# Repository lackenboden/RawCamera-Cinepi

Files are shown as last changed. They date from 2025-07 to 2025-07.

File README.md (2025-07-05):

# Compact 3D printed enclosure/sensormount for a barebones IMX585 [Cinepi](https://github.com/cinepi/cinepi-raw) camera.

Everything

## Features:

    • Spring adjustable C-Mount
    • Raw recording Capabilities (4K 12Bit - 1/1.2 inch sensor)
    • Internal Storage on NVME 2280 SSD
    • NPF battery compatibility
    • Display via Smartphone
    • Lots of mounting points for addons

## Software

>	[Cinemate](https://github.com/Tiramisioux/cinemate/tree/main) by Tiramisioux - A simple gui built ontop of cinepi-raw for control via wifi or screen <br>
>	 [Cinepi-raw](https://github.com/cinepi/cinepi-raw) by Schoolpost - Image capture and control interfaces - Makes raw recording possible
>	<br> <br>
>	Thanks for providing the software for us ♥

## Addons (for now):
Addons

    • Grip
    • Adaptor for a DJI ronin RS3 phoneholder

## Printing Materials

    • Use a material of your liking for most of the parts
    • TPU of softness of at least 88A (Springs and Rubbercover need to be printed from TPU)

## BOM:
**1x CinepiCamera_Straight_Mainbody.stl**<br>
	&nbsp;&nbsp;&nbsp;&nbsp;6x ruthex - RX-1/4-20x12,7 – Quarter inch threaded inserts<br>
	&nbsp;&nbsp;&nbsp;&nbsp;8x ruthex – RX-M3x5_7 – M3 threaded insert short<br>
1x Adjustablemount_C_Springs_2 (assembly)<br>
	&nbsp;&nbsp;&nbsp;&nbsp;1x SE-SB8M-IMX585 (notes in assembly guide)<br>
	&nbsp;&nbsp;&nbsp;&nbsp;**3x Adjustablemount_C_Springs_TpuSpring.stl** !Caution print in 88A or similar TPU!<br>
	&nbsp;&nbsp;&nbsp;&nbsp;3x M2x10 flat head screw<br>
	&nbsp;&nbsp;&nbsp;&nbsp;**1x Adjustablemount_C_Springs_Rubbercover.stl** (notes in assembly guide)<br>
	&nbsp;&nbsp;&nbsp;&nbsp;**1x Adjustablemount_C_Springs_Gluebase.stl** (notes in assembly guide)<br>
	&nbsp;&nbsp;&nbsp;&nbsp;**1x Adjustablemount_C_Springs__Filterholder.stl** (notes in assembly guide)<br>
	&nbsp;&nbsp;&nbsp;&nbsp;&nbsp;&nbsp;&nbsp;&nbsp;	1x IR-Cut Filterglass (18x15mm)<br>
	&nbsp;&nbsp;&nbsp;&nbsp;&nbsp;&nbsp;&nbsp;&nbsp;  2x M2x4 Flat head screws<br>
8x M2x4 Flat head screws<br>
**1x CinepiCamera_Straight_Batterycompartment.stl**<br>
	&nbsp;&nbsp;&nbsp;&nbsp;1x ruthex – RX-M3x5_7 – M3 threaded insert short<br>
	&nbsp;&nbsp;&nbsp;&nbsp;2x 2.6mm banana plug (notes in assembly guide) – eg. RS: 2080217<br>
	&nbsp;&nbsp;&nbsp;&nbsp;2x ISO 4762 M2x8 cylindrical head screw<br>
	&nbsp;&nbsp;&nbsp;&nbsp;1x CK1408 dcdc 5V stepdown converter<br>
	&nbsp;&nbsp;&nbsp;&nbsp;1x Raspberry Pi 5 B 8GB<br>
	&nbsp;&nbsp;&nbsp;&nbsp;&nbsp;&nbsp;&nbsp;&nbsp;	1x Pineboards HatDrive! Bottom<br>
	&nbsp;&nbsp;&nbsp;&nbsp;&nbsp;&nbsp;&nbsp;&nbsp;	1x Samsung 970 EVO Plus - 2 TB 2280 SSD (or alternatives if compatible)<br>
	&nbsp;&nbsp;&nbsp;&nbsp;&nbsp;&nbsp;&nbsp;&nbsp;	1x Raspberry Pi active cooler for RPI5<br>
	&nbsp;&nbsp;&nbsp;&nbsp;	4x ISO 4762 M2.5x16<br>
	&nbsp;&nbsp;&nbsp;&nbsp;**1x CinepiCamera_Batterydoor.stl**<br>
	&nbsp;&nbsp;&nbsp;&nbsp;1x ISO 4762 M3x10 cylindrical head screw<br>
4x ISO 4762 M3x10 cylindrical head screw<br>
**1x CinepiCamera_Straight_Top.stl**<br>
	&nbsp;&nbsp;&nbsp;&nbsp;3x ruthex - RX-1/4-20x12,7 – Quarter inch threaded inserts<br>
	&nbsp;&nbsp;&nbsp;&nbsp;4x ruthex – RX-M3x5_7 – M3 threaded insert short<br>
4x ISO 4762 M3x10 cylindrical head screw<br>
<br>
Sony NP-F750 batteries (or other sizes of batteries – NP-F750 is flush with the camera)<br>
<br>

## BOM Addons:

**1xCinepiCamera_Straight_Grip.stl**<br>
	1x ruthex - RX-1/4-20x12,7 – Quarter inch threaded insert<br>
4x ISO 4762 M3x10 cylindrical head screw<br>
<br>
**1x CinepiCamera_Straight_RoninPhoneholder.stl**<br>
	1x ruthex - RX-1/4-20x12,7 – Quarter inch threaded insert<br>
1x Tripod screw with cylinder head (or fitting alternatives)<br>
<br>
<br>

## Assembly guide

## Converting the CS Mount on the IMX585 Board to C Mount

CS-Mount Soho
CS-Mount Soho Back
<br><br>
>Remove the M2 screws from the back of the IMX585 PCB<br>
>Preheat your 3D printer bed to the maximum level supported by it (without destroying your printer bed) - I used 120 °C<br>
>Place down the aluminum mount face down onto the hotbed and leave it there for a few minutes to weaken the glue<br>
>
>Use a sharp prying tool to remove the aluminium mount from the pcb while still warm - Start prying on the edges - Dont use too much force!<br>
<br>

Cs-CmountIMX585_5

>Use a M2 screw (or tap) and form the threads on the **Adjustablemount_C_Springs_Gluebase.stl** (pictured red)
>Use glue or silicone (neutral cure to not damage the aluminium?) and fix it to the removed CS mount
<br>

Filterholder Exchangable

>Cut the IR Filterglass to size (18x15mm)
>Glue it to the **Filterholder Exchangable.stl**

Cs-CmountIMX585_4

>Use three **Adjustablemount_C_Springs_TpuSpring.stl** and M2x10 screws and fix the sensor to the mount<br>

Cs-CmountIMX585_2

>Add the **Adjustablemount_C_Springs_Rubbercover.stl** by using either M2x8 screws or glueing it to the sensor board<br>
>Use electrical tape or similar to remove light leaks after adjusting the mount<br>

<br>
<br>
<br>

Shield: [][cc-by-nc-sa]

This work is licensed under a
[Creative Commons Attribution-NonCommercial-ShareAlike 4.0 International License][cc-by-nc-sa].

[][cc-by-nc-sa]

[cc-by-nc-sa]: http://creativecommons.org/licenses/by-nc-sa/4.0/
[cc-by-nc-sa-image]: https://licensebuttons.net/l/by-nc-sa/4.0/88x31.png
[cc-by-nc-sa-shield]: https://img.shields.io/badge/License-CC%20BY--NC--SA%204.0-lightgrey.svg

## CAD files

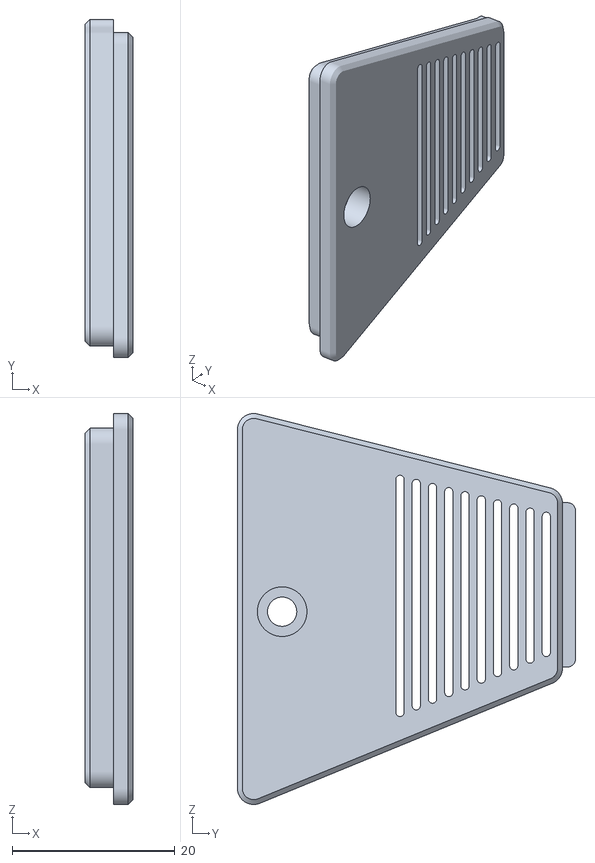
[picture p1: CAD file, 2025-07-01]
CinepiCamera_Batterydoor.stl
5.90 x 41.6 x 48.1

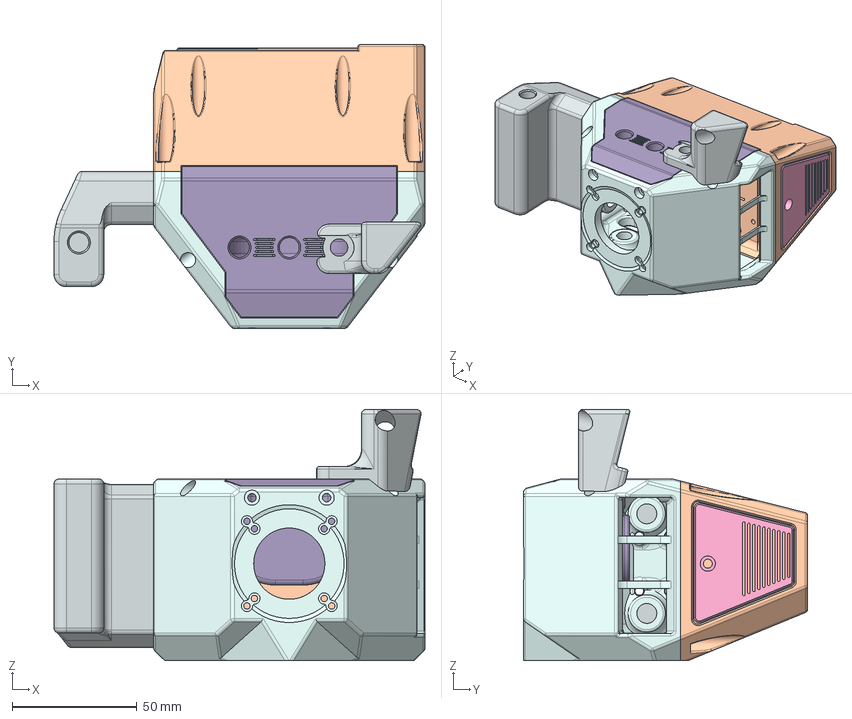
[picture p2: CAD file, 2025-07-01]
CinepiCamera.stp
149.0 x 114.0 x 101.0 mm

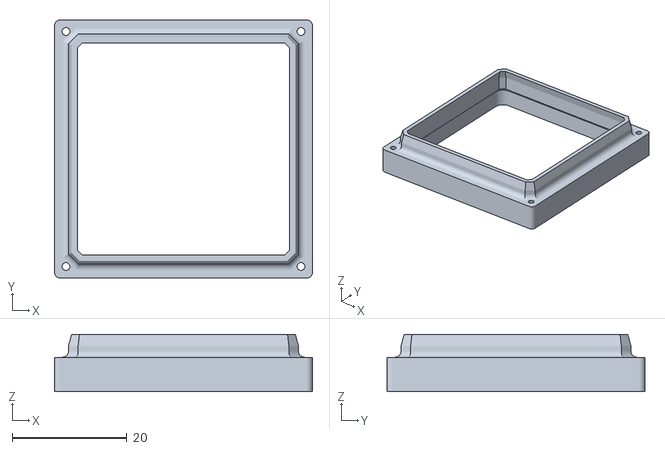
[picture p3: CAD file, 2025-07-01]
Adjustablemount_C_Springs_Rubbercover.stl
45.0 x 45.0 x 10.0

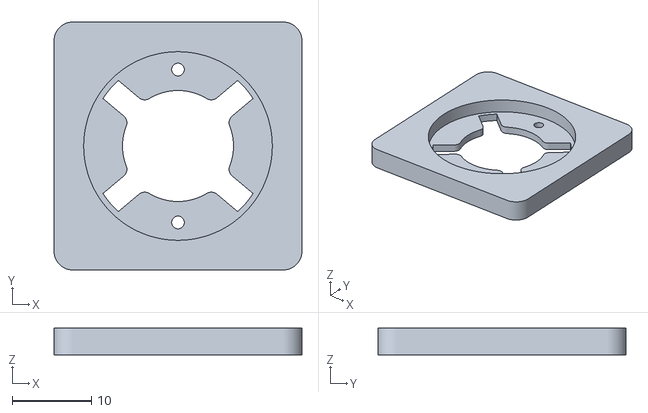
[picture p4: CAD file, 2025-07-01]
Adjustablemount_C_Springs_Gluebase.stl
31.3 x 31.3 x 3.40

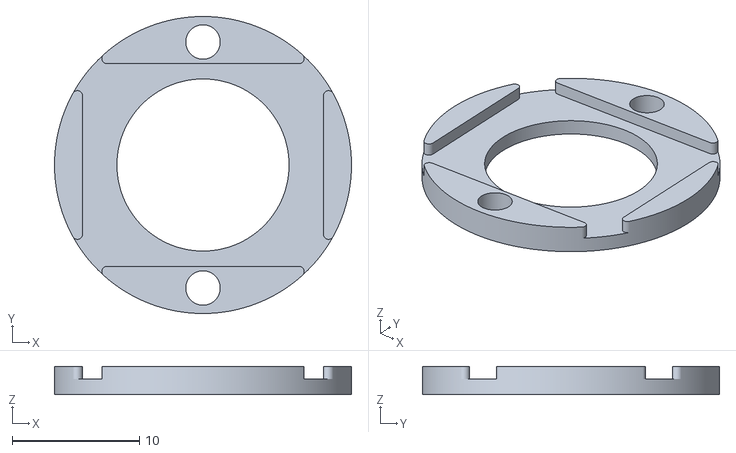
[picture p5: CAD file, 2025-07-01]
Adjustablemount_C_Springs__Filterholder.stl
23.3 x 23.3 x 2.20

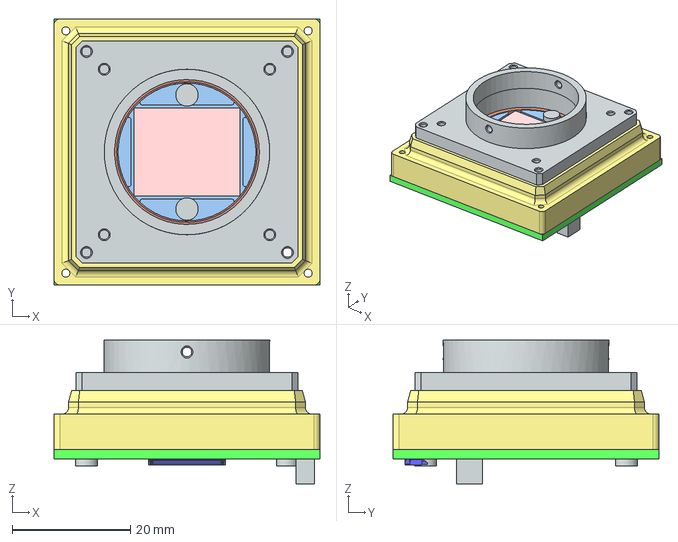
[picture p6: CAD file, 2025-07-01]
Adjustablemount_C_Springs_2.stp
45.0 x 45.0 x 24.3 mm

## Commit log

2025-07-02 Adding BOM
    Adding BOM and pictures
2025-07-04 Update README.md
    Add parts of Sensor assembly guide

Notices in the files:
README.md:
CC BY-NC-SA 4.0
